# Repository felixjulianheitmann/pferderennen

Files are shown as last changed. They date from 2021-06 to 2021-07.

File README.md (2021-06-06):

# Pferderennen - Horse Racing

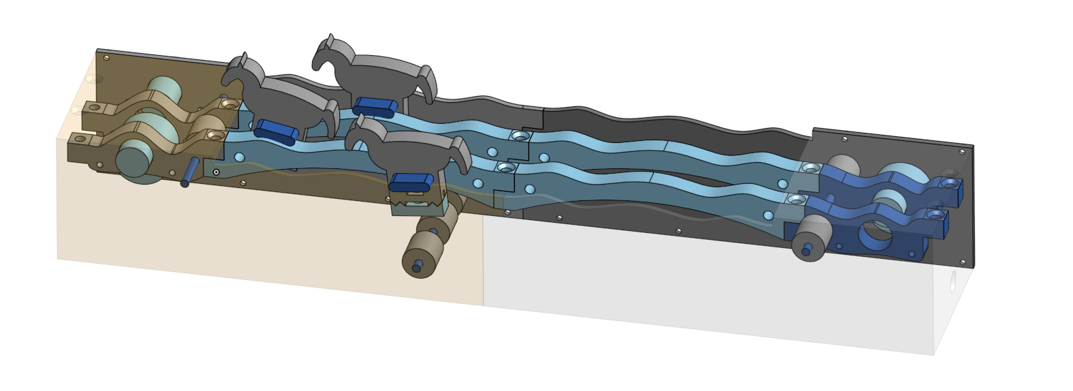
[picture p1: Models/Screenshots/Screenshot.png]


This small project takes an arduino and as many stepper motors as you like. The ones I used here are **28BYJ-48** with an **ULN2003** as the motor driver. Other motors should be supported by implementing the [HorseDriver.h](Firmware/src/modules/HorseDriver.h) interface.

All source code is found under [Firmware](Firmware), while all 3D models as well as a technical sketch and a screenshot of the finished model reside in [Models](Models).

Start and Finish trigger are built as screws which are connected to ground. The Arduino nano connections are:

| Arduino | Other |
| --- | --- |
| Vin | VCC |
| D2 | Start button |
| D3 | M1 IN4 |
| D4 | Reset button |
| D5 | Trigger H1 |
| D6 | |
| D7 | Trigger H2 |
| D8 | Trigger H3 |
| D9 | H1 IN3 |
| D10 | H1 IN1 |
| D11 | H1 IN2 |
| D12 | H1 IN4 |
| D13 | H2 IN3 |
| A0 | H2 IN1 |
| A1 | H2 IN2 |
| A2 | H2 IN4 |
| A3 | H3 IN3 |
| A4 | H3 IN1 |
| A5 | H3 IN2 |

The connections can be modified in [globals.h](Firmware/src/config/globals.h). All stepper drivers are connected to VCC.

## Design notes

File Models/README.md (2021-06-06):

# Models

Here are the 3D models needed for the horse racing track.

They are:

| Part | Amount | Image |
| --- | --- | --- |
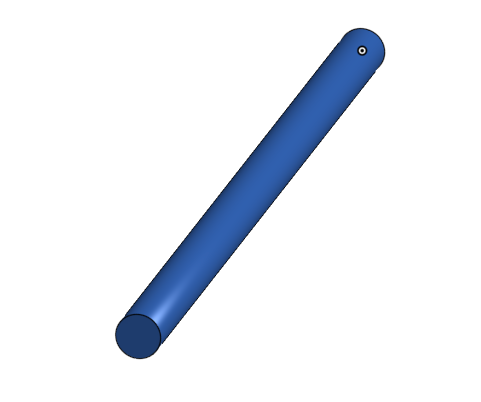
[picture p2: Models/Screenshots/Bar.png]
Bar
| Bar | 3x |  |
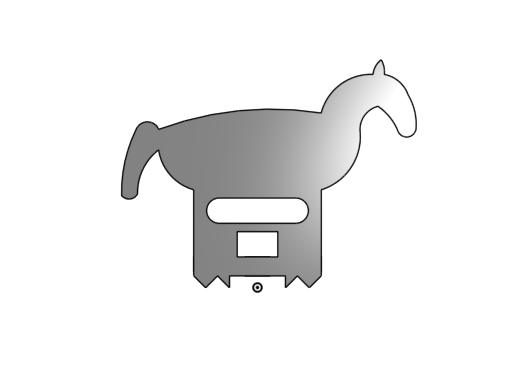
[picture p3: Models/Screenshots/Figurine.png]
Figurine
| Figurine | 3x |  |
| Grip_Lower | 3x | Grip_lower |
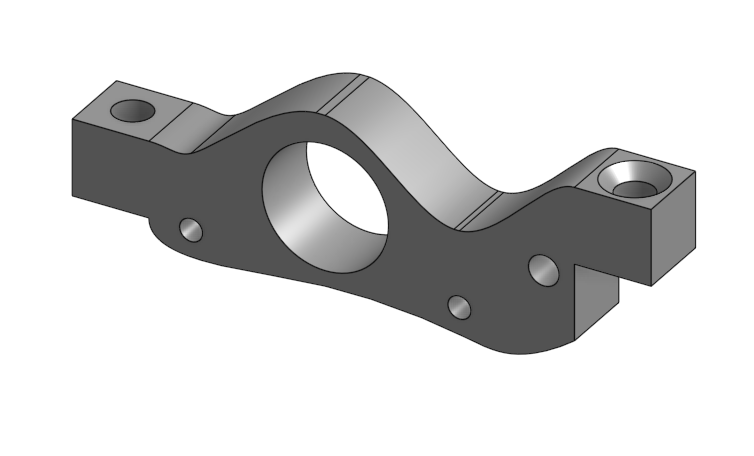
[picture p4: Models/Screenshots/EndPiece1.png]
EndPiece1
| EndPiece 1 | 2x |  |
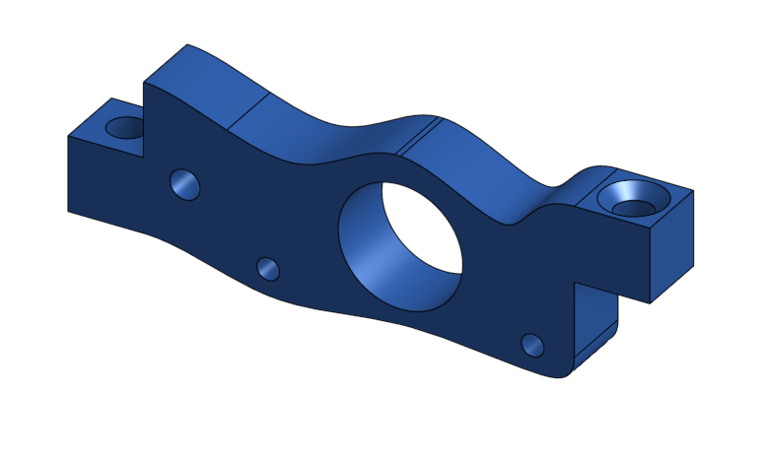
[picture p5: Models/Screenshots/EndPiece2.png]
EndPiece2
| EndPiece 2 | 2x |  |
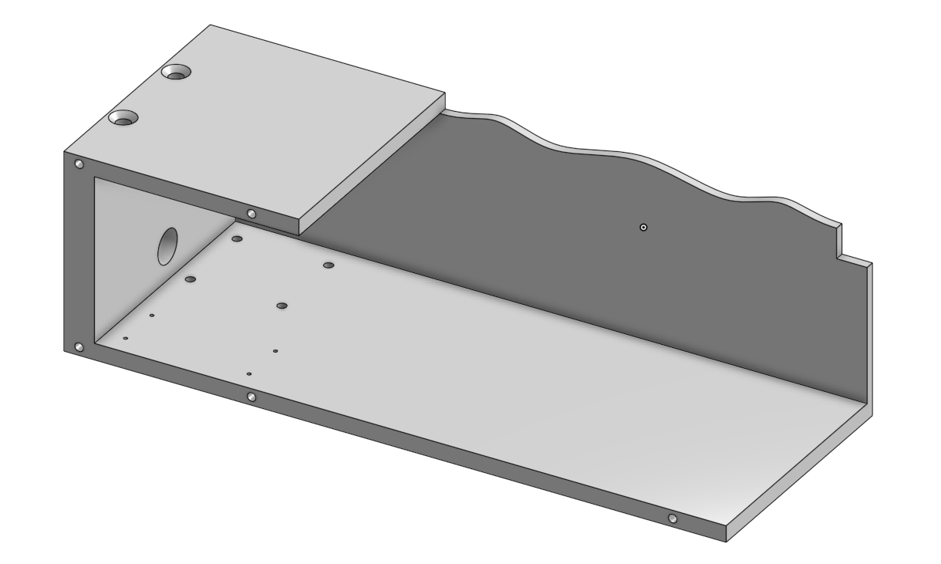
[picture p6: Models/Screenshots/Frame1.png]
Frame1
| Track Frame 1 | 1x |  |
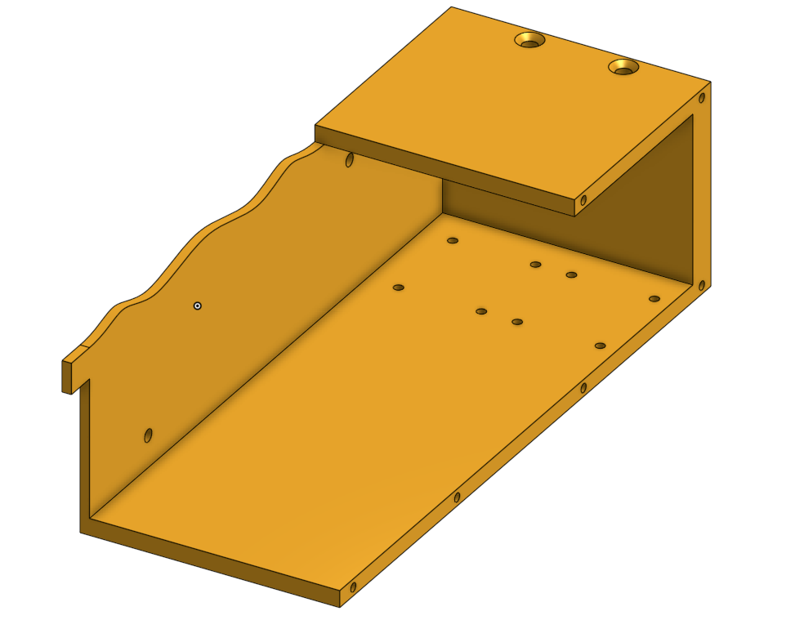
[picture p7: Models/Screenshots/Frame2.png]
Frame2
| Track Frame 2 | 1x |  |
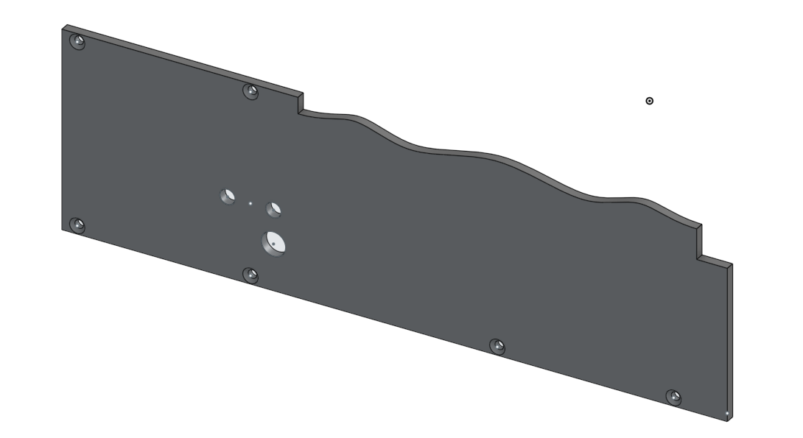
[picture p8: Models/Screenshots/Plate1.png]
Plate1
| Track Plate 1 | 1x |  |
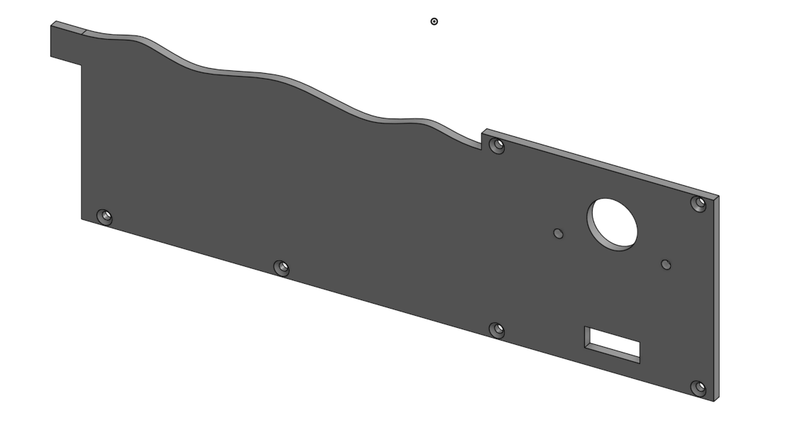
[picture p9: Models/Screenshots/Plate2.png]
Plate2
| Track Plate 2 | 1x |  |
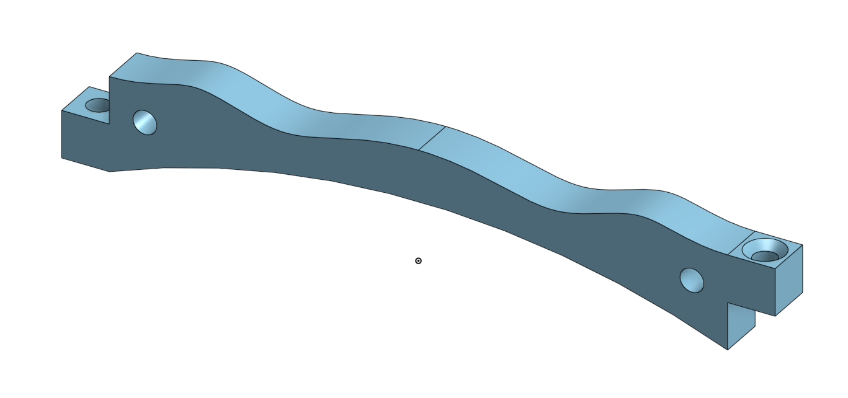
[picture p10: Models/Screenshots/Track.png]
Track
| Track_Section | 4x |  |

Furthermore, you need

| Part | Amount |
| --- | --- |
| Stepper motor | 3x |
| Stepper motor driver | 3x |
| Arduino Nano | 1x |
| M5x40 flathead screw | ~12 |
| M5 nut | ~4 |
| M3x10 flathead screw | ~24 |
| M3 nut | ~12 |
| 2mm nail | ~4 |
| Lots of wires | Lots |

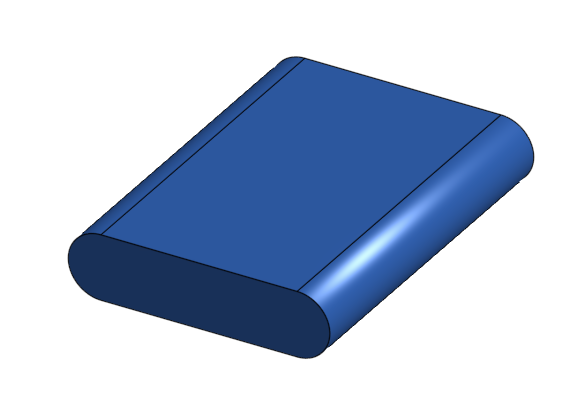
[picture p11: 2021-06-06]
Models/Screenshots/Guidance.png

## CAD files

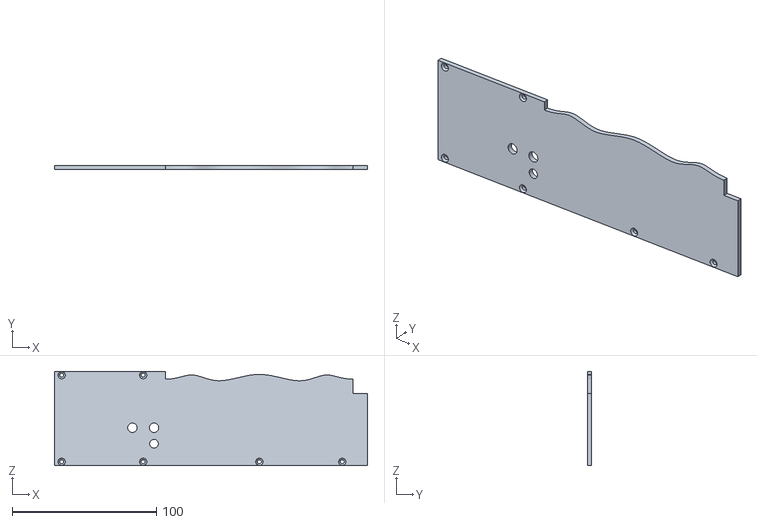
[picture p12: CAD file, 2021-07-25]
Models/Track_Plate1.stl
217.0 x 3.00 x 65.4

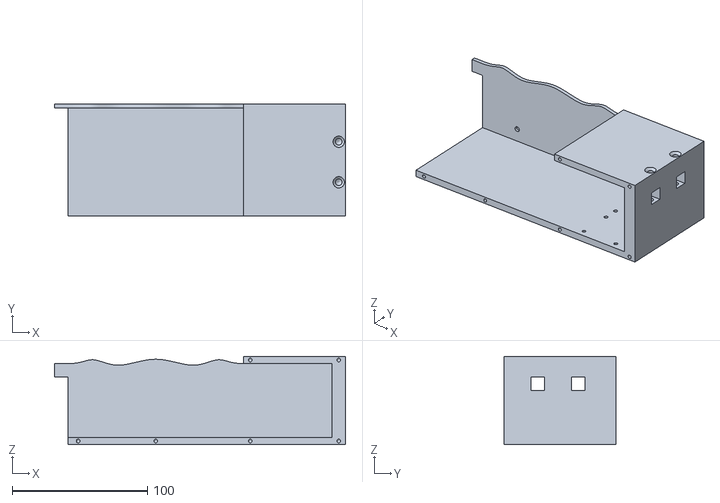
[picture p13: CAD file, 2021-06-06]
Models/Track_Frame2.stl
215.5 x 83.0 x 65.4

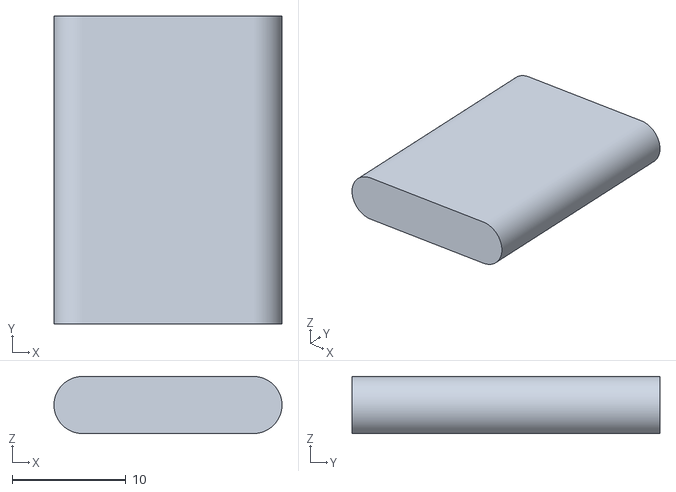
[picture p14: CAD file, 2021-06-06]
Models/Pferd_Guidance.stl
20.0 x 27.0 x 5.00

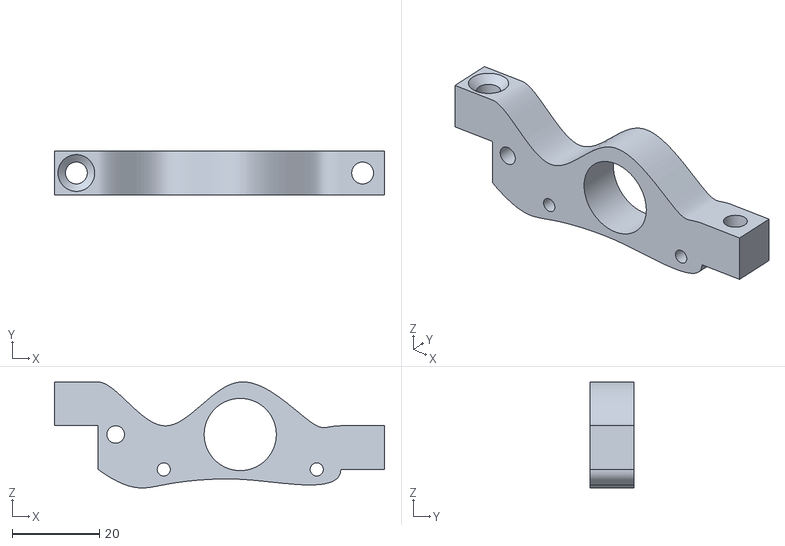
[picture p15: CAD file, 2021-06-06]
Models/Track_EndPiece1.stl
75.5 x 10.0 x 24.2

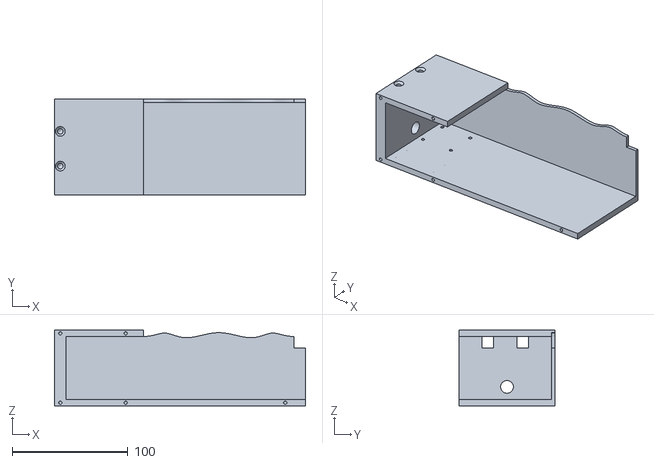
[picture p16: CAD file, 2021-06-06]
Models/Track_Frame1.stl
217.0 x 83.0 x 65.4

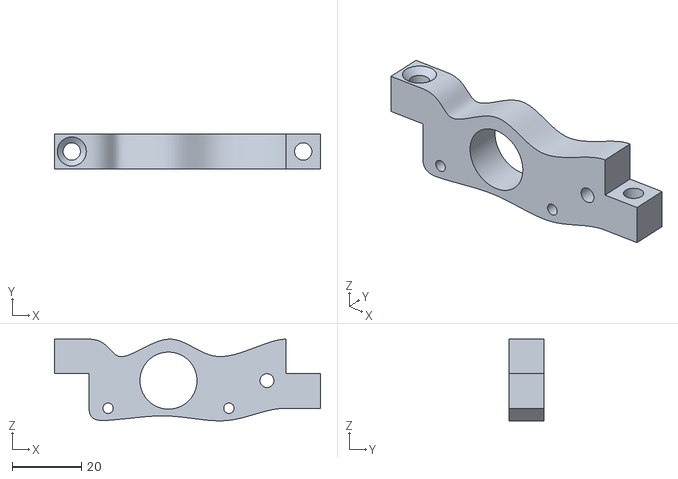
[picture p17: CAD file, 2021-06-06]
Models/Track_EndPiece2.stl
77.0 x 10.0 x 23.6

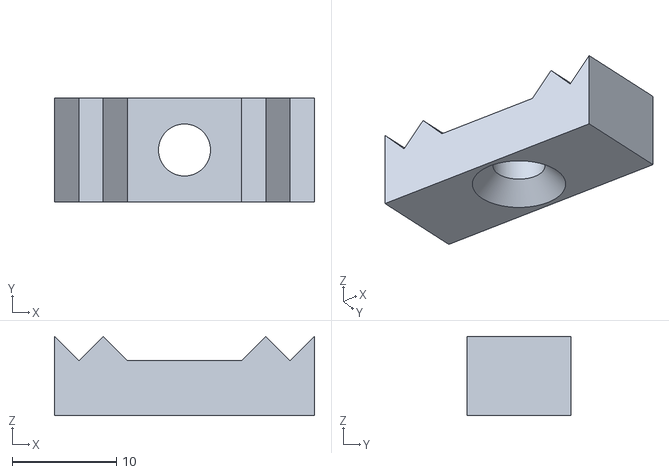
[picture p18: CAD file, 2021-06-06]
Models/Pferd_Grip_Lower.stl
25.0 x 10.0 x 7.60

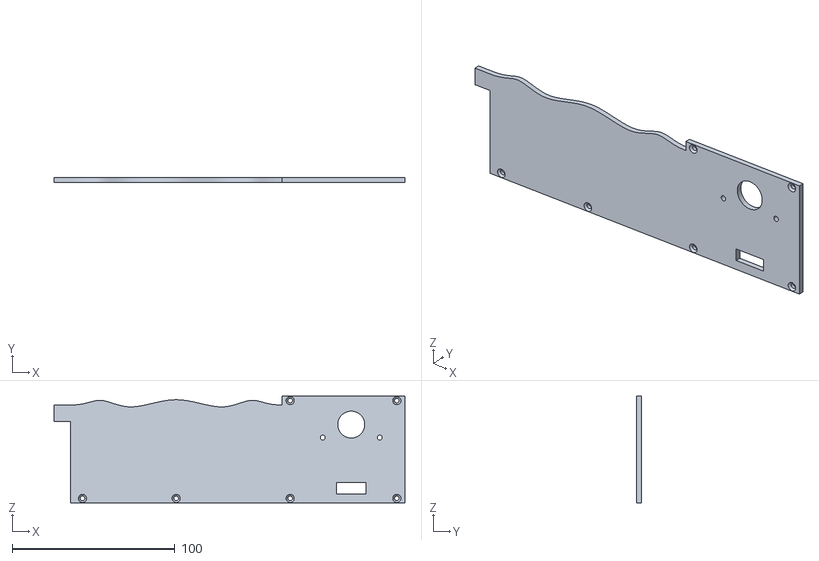
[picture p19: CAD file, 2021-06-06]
Models/Track_Plate2.stl
215.5 x 3.00 x 65.4

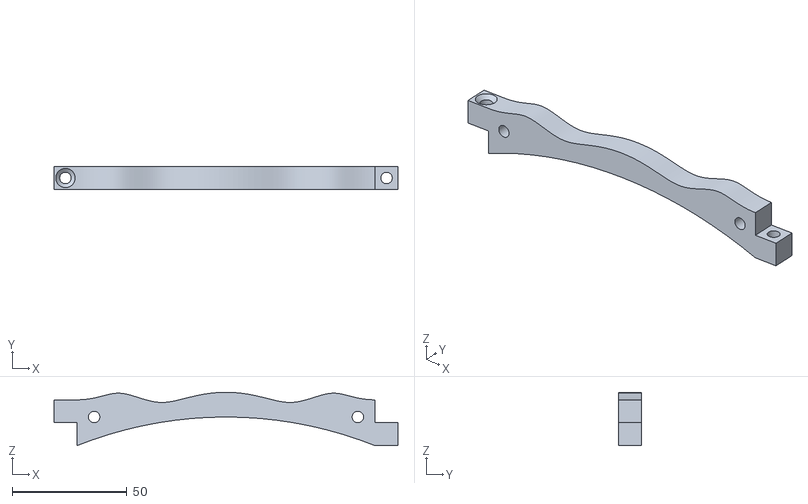
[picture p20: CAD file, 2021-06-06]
Models/Track_Section.stl
150.0 x 10.0 x 23.3

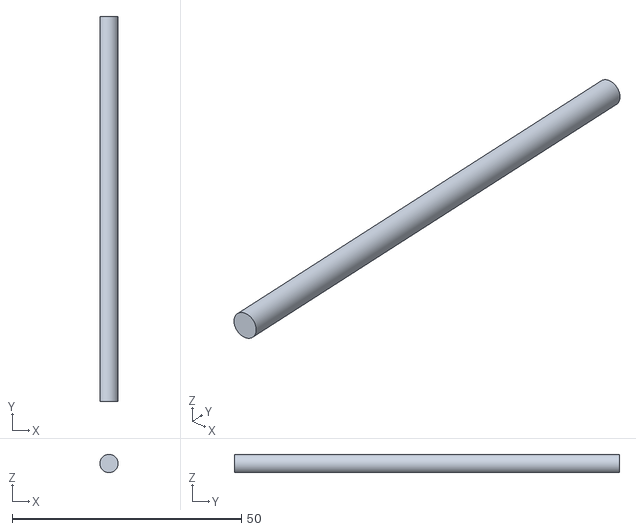
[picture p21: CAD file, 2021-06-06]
Models/Parts_Bar.stl
4.00 x 84.0 x 4.00

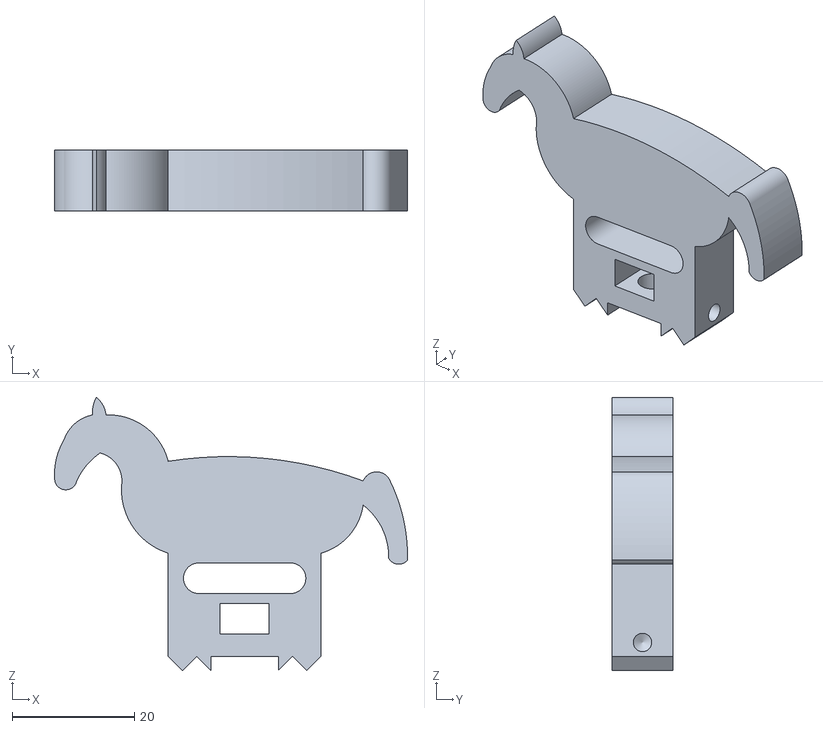
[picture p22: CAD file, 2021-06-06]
Models/Pferd_Figurine.stl
57.7 x 10.0 x 44.7

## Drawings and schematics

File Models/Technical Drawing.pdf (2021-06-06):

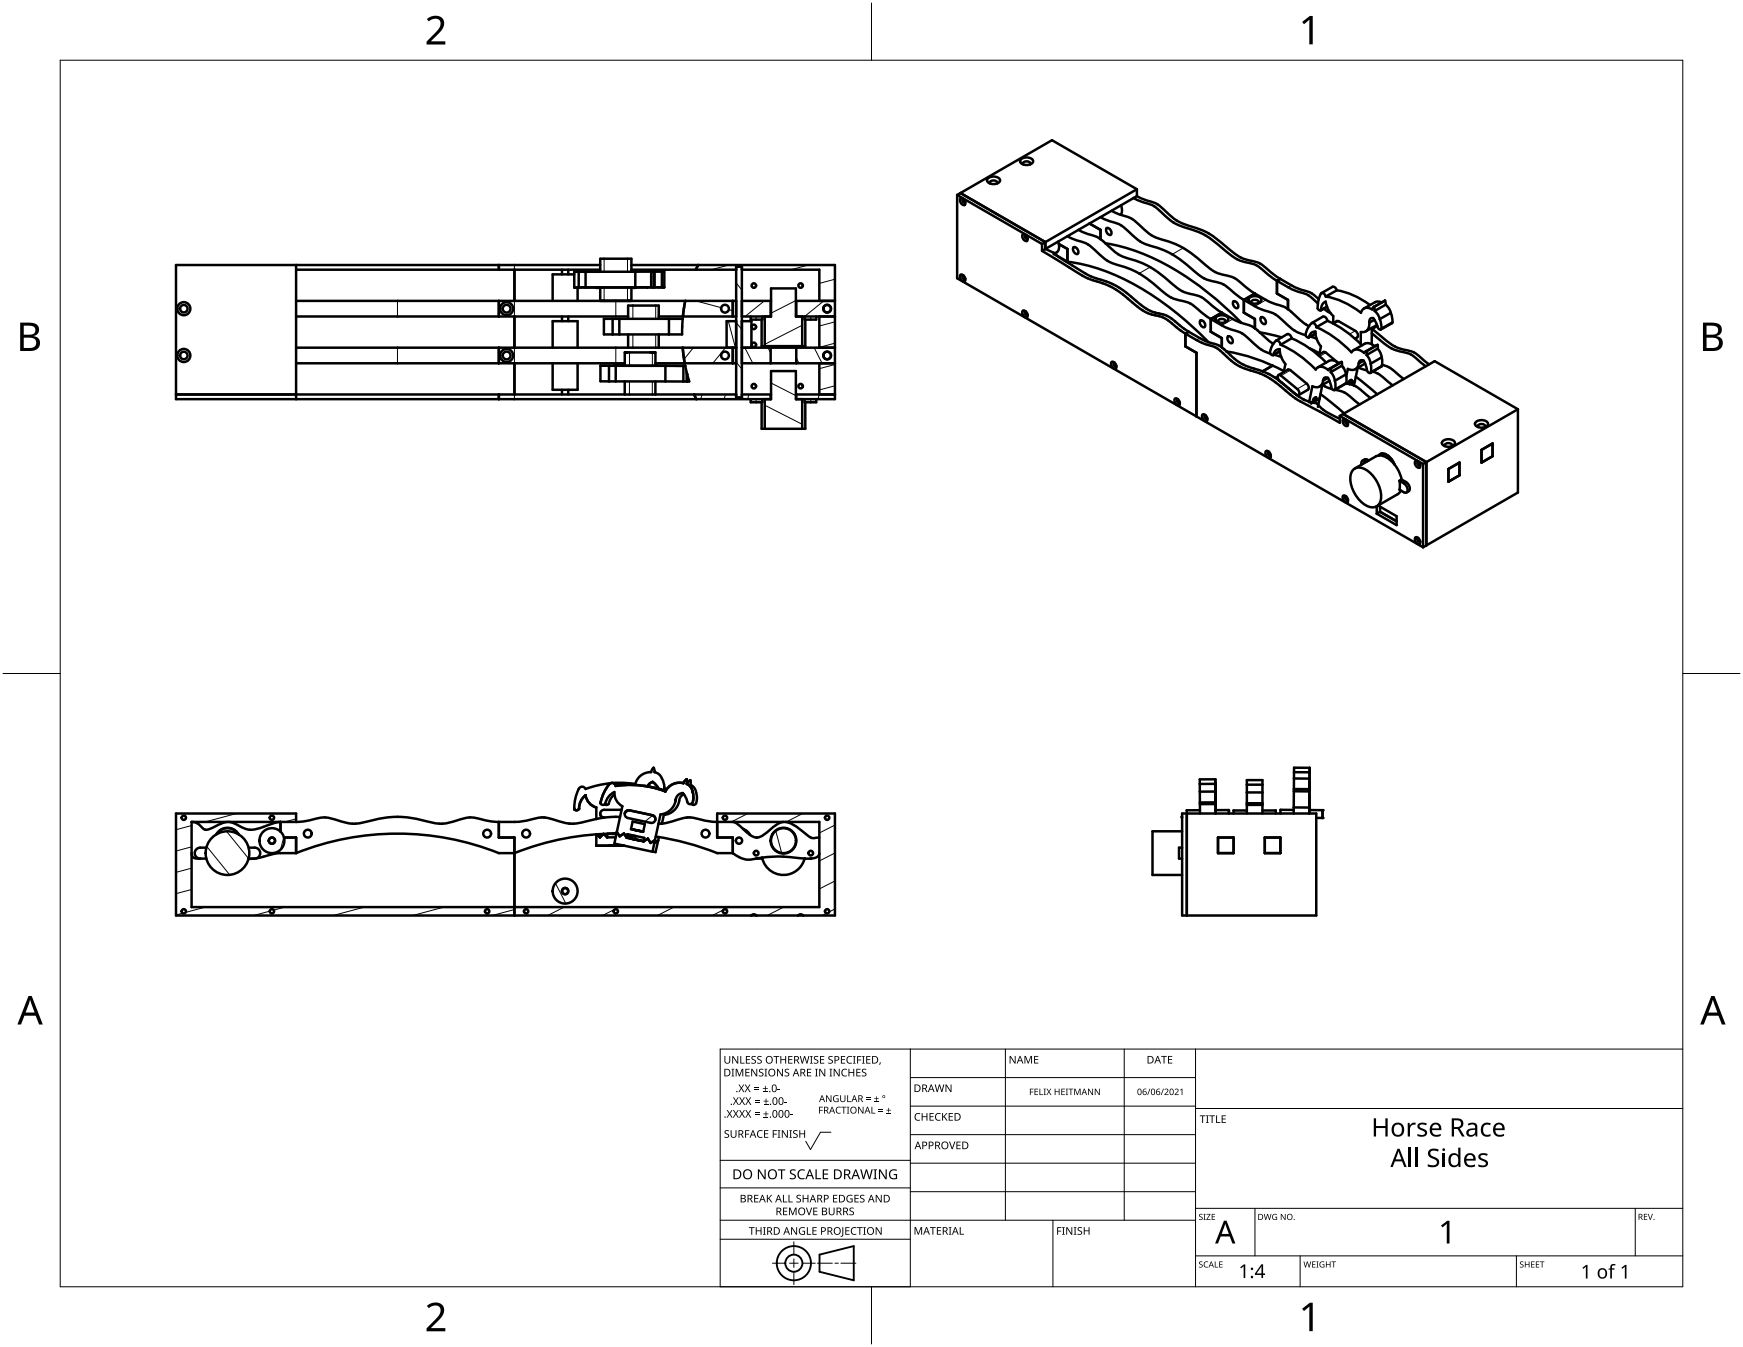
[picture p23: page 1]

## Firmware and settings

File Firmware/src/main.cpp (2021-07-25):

// ######################################################
// Author: Felix Heitmann (felixjulianheitmann@gmail.com)
// Creation date: 22.05.2021
// ######################################################

#include <Arduino.h>
#include <config/globals.h>
#include <modules/GameEngine.h>



// ##########################################################
// ### Function Prototypes
// ##########################################################
bool startButtonPressed();
bool resetButtonPressed();
bool horseTriggered(HorseIdx idx);
void setPinModes();


// ##########################################################
// ### Initialize program variables
// ##########################################################

auto game  = GameEngine();

bool lastStartButtonState = true;
bool lastResetButtonState = true;
bool lastTriggerState[Globals::GameControl::nHorses] = { true };

// ##########################################################
// ### Program setup
// ##########################################################
void setup() {

    Serial.begin(115200);
    Serial.println("########################################");
    Serial.println("# Welcome to the Horse track           #");
    Serial.println("########################################");

    Serial.println("# Setting up horse positions ... ");

    // +++ Set pin modes
    setPinModes();

    // +++ Reset Horses to start
    game.reset();

    Serial.println("# Enter loop ...");

}



// ##########################################################
// ### Program loop
// ##########################################################
void loop() {

    if(startButtonPressed()) game.start();  // If start button is pressed, start the game
    if(resetButtonPressed()) game.reset();  // If reset button is pressed, reset the game
    for(unsigned int idx = 0; idx < Globals::GameControl::nHorses; ++idx)
        if(horseTriggered(idx)) game.triggerHorse(idx);

    // // set rpm according to potentiometer
    // auto input = analogRead(Globals::GameControl::VelocityPotentiometer) / 1023.0f;
    // game.setGameSpeed(input);
    // game.setGameSpeed(1.0f);

    // iterative call to driver to trigger periodic behaviour
    game.loopCall();

}



// ##########################################################
// ### Function Definitions
// ##########################################################
bool startButtonPressed()
{
    // randomSeed(micros());
    bool buttonPressed = ( lastStartButtonState && !digitalRead(Globals::GameControl::StartButton) );
    lastStartButtonState = digitalRead(Globals::GameControl::StartButton);
    return buttonPressed;
}

bool resetButtonPressed()
{
    bool buttonPressed = ( lastResetButtonState && !digitalRead(Globals::GameControl::ResetButton) );
    lastResetButtonState = digitalRead(Globals::GameControl::ResetButton);
    return buttonPressed;
}

bool horseTriggered(HorseIdx idx) 
{
    bool now = (digitalRead(Globals::GameControl::horseTriggers[idx]));
    bool triggered = ( lastTriggerState[idx] && !now );
    lastTriggerState[idx] = now;
    return triggered;
}

void setPinModes()
{
    pinMode(Globals::GameControl::StartButton, INPUT_PULLUP);
    pinMode(Globals::GameControl::ResetButton, INPUT_PULLUP);
    pinMode(Globals::GameControl::VelocityPotentiometer, INPUT);

    for(auto& pin : Globals::GameControl::horseTriggers)
    {
        pinMode(pin, INPUT_PULLUP);
    }

    for(auto& pinSet : Globals::Motor::MotorPins)
    {
        for(auto& pin : pinSet)
        {
            pinMode(pin, OUTPUT);
        }
    }
}

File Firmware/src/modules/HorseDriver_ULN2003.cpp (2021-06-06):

// ######################################################
// Author: Felix Heitmann (felixjulianheitmann@gmail.com)
// Creation date: 22.05.2021
// ######################################################

#include <modules/HorseDriver_ULN2003.h>
#include <config/globals.h>
#include <Stepper.h>

// Maps a floating point value
float mapf(float x, float in_min, float in_max, float out_min, float out_max)
{
  return (x - in_min) * (out_max - out_min) / (in_max - in_min) + out_min;
}

HorseDriver_ULN2003::HorseDriver_ULN2003(const Pin pins[4], bool const dir)
    : HorseDriver()
    , _state(Stop)
    , _velocity(0.0f)
    , _dir(dir)
    , _pins{ pins[0], pins[1], pins[2], pins[3] }
    , _step(0)
    , _lastStepTime(0)
{
}

void HorseDriver_ULN2003::init()
{

}

void HorseDriver_ULN2003::loopCall()
{
    // Move the stepper if enabled
    if(_state != Stop)
    {
        if(_state == Forward)
        {
            step(_dir ? true : false);
        }
        else if(_state == Reverse)
        {
            step(_dir ? false : true);
        }
    }
}

void HorseDriver_ULN2003::setVelocity(float velocity)
{
    _velocity = velocity;
}

void HorseDriver_ULN2003::forward()
{
    _state = Forward;
}

void HorseDriver_ULN2003::reverse()
{
    _state = Reverse;
}

void HorseDriver_ULN2003::stop()
{
    _state = Stop;
}

void HorseDriver_ULN2003::step(bool const dir)
{

    // Execute only when the interval is exceeded.
    // This gives a velocity defined behaviour
    // Serial.println("V: " + String(_velocity));
    if(micros() - _lastStepTime < ( Globals::Motor::Delay / _velocity )) return;
    _lastStepTime = micros();

    // increment or decrement step in range 0 - 4
    if(dir) _step = ( _step + 1 ) % 4;
    else --_step;
    if(_step == -1) _step = 3;


    /* Stepping order
    * Step C0 C1 C2 C3 (A, A*, B, B*)
    *    1  1  0  1  0
    *    2  0  1  1  0
    *    3  0  1  0  1
    *    4  1  0  0  1
    */
    switch(_step)
    {
    case 0: // 1010
        digitalWrite(_pins[0], HIGH);
        digitalWrite(_pins[1], LOW);
        digitalWrite(_pins[2], HIGH);
        digitalWrite(_pins[3], LOW);
        break;
    case 1: // 0110
        digitalWrite(_pins[0], LOW);
        digitalWrite(_pins[1], HIGH);
        digitalWrite(_pins[2], HIGH);
        digitalWrite(_pins[3], LOW);
        break;
    case 2: // 0101
        digitalWrite(_pins[0], LOW);
        digitalWrite(_pins[1], HIGH);
        digitalWrite(_pins[2], LOW);
        digitalWrite(_pins[3], HIGH);
        break;
    case 3: // 1001
        digitalWrite(_pins[0], HIGH);
        digitalWrite(_pins[1], LOW);
        digitalWrite(_pins[2], LOW);
        digitalWrite(_pins[3], HIGH);
        break;
    }

}

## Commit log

2021-06-06 First functional prototype. Changed the wiring a little
2021-06-06 Added the Models, a technical drawing and a screenshot
    [Parts_Bar.stl, Pferd_Figurine.stl, Pferd_Grip_Lower.stl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]
2021-06-06 Removed Stepper dependency
2021-06-06 Added Screenshots for the parts Commit 2
    [Track_Frame2.stl]
2021-06-07 Löcher angefügt für Taster/Schalter
    [Track_Plate1.stl]
2021-07-25 Updated parts slighlty and updated config.
    [Track_Plate1.stl]
